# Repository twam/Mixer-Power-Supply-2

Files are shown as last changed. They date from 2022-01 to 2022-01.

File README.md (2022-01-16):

Mixer-Power-Supply-2
===

This repository is part of the USB audio mixer project described on https://www.twam.info/general/building-a-custom-usb-audio-mixer.

It supersedes http://github.com/twam/Mixer-Power-Supply.

## License

[][cc-by-sa]

This work is licensed under a [Creative Commons Attribution-NonCommercial-ShareAlike 4.0 International License][cc-by-sa].

[][cc-by-sa]

[cc-by-sa]: http://creativecommons.org/licenses/by-nc-sa/4.0/
[cc-by-sa-image]: https://licensebuttons.net/l/by-nc-sa/4.0/88x31.png
[cc-by-sa-shield]: https://img.shields.io/badge/License-CC%20BY--NC--SA%204.0-lightgrey.svg

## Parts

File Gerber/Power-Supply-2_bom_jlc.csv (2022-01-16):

Comment | Designator | Footprint | LCSC Part #
10u/50V | C1,C2,C3,C5,C6,C7 | C_1206_3216Metric | C13585
100nF | C4,C19,C8,C20,C21,C22,C11,C28,C29,C12,C30,C31,C32,C33 | C_0603_1608Metric | C14663
4u7 | C34 | C_0805_2012Metric | C1779
LL4148 | D1,D2,D3,D4,D12 | D_MiniMELF | C9808
green | D7 | LED_0603_1608Metric | C72043
red | D8,D9,D10,D11 | LED_0603_1608Metric | C2286
600R/100M | L5 | L_0805_2012Metric | C1017
AO3400A | Q1,Q2,Q3,Q5,Q4 | TSOT-23 | C20917
0R | R1,R15,R7,R22,R26,R20,R31,R34,R37 | R_0805_2012Metric | C17477
2k4 | R2 | R_0603_1608Metric | C22940
22k | R3 | R_0603_1608Metric | C31850
270k | R4,R17 | R_0603_1608Metric | C22965
3k3 | R5 | R_0805_2012Metric | C26010
11k | R6,R11,R25,R27 | R_0603_1608Metric | C25950
27k | R8 | R_0603_1608Metric | C22967
39k | R9 | R_0805_2012Metric | C23153
6k8 | R10,R28 | R_0603_1608Metric | C23212
39k | R12 | R_0603_1608Metric | C23153
0R01 | R13,R29 | R_1206_3216Metric | C308574
5k6 | R14,R36,R39,R41,R42,R43,R44 | R_0603_1608Metric | C23189
10k | R16,R23,R21,R24,R32,R33,R35,R40,R38 | R_0603_1608Metric | C25804
68k | R19,R30 | R_0603_1608Metric | C23231
1k5 | R45 | R_0603_1608Metric | C22843
RESET | SW1 | SW_SPST_B3U-1000P | C231329
INA139 | U5,U9 | SOT-23-5 | C129947
NE5532 | U7 | SOIC-8_3.9x4.9mm_P1.27mm | C7426
MCP6002-xSN | U10 | SOIC-8_3.9x4.9mm_P1.27mm | C7377

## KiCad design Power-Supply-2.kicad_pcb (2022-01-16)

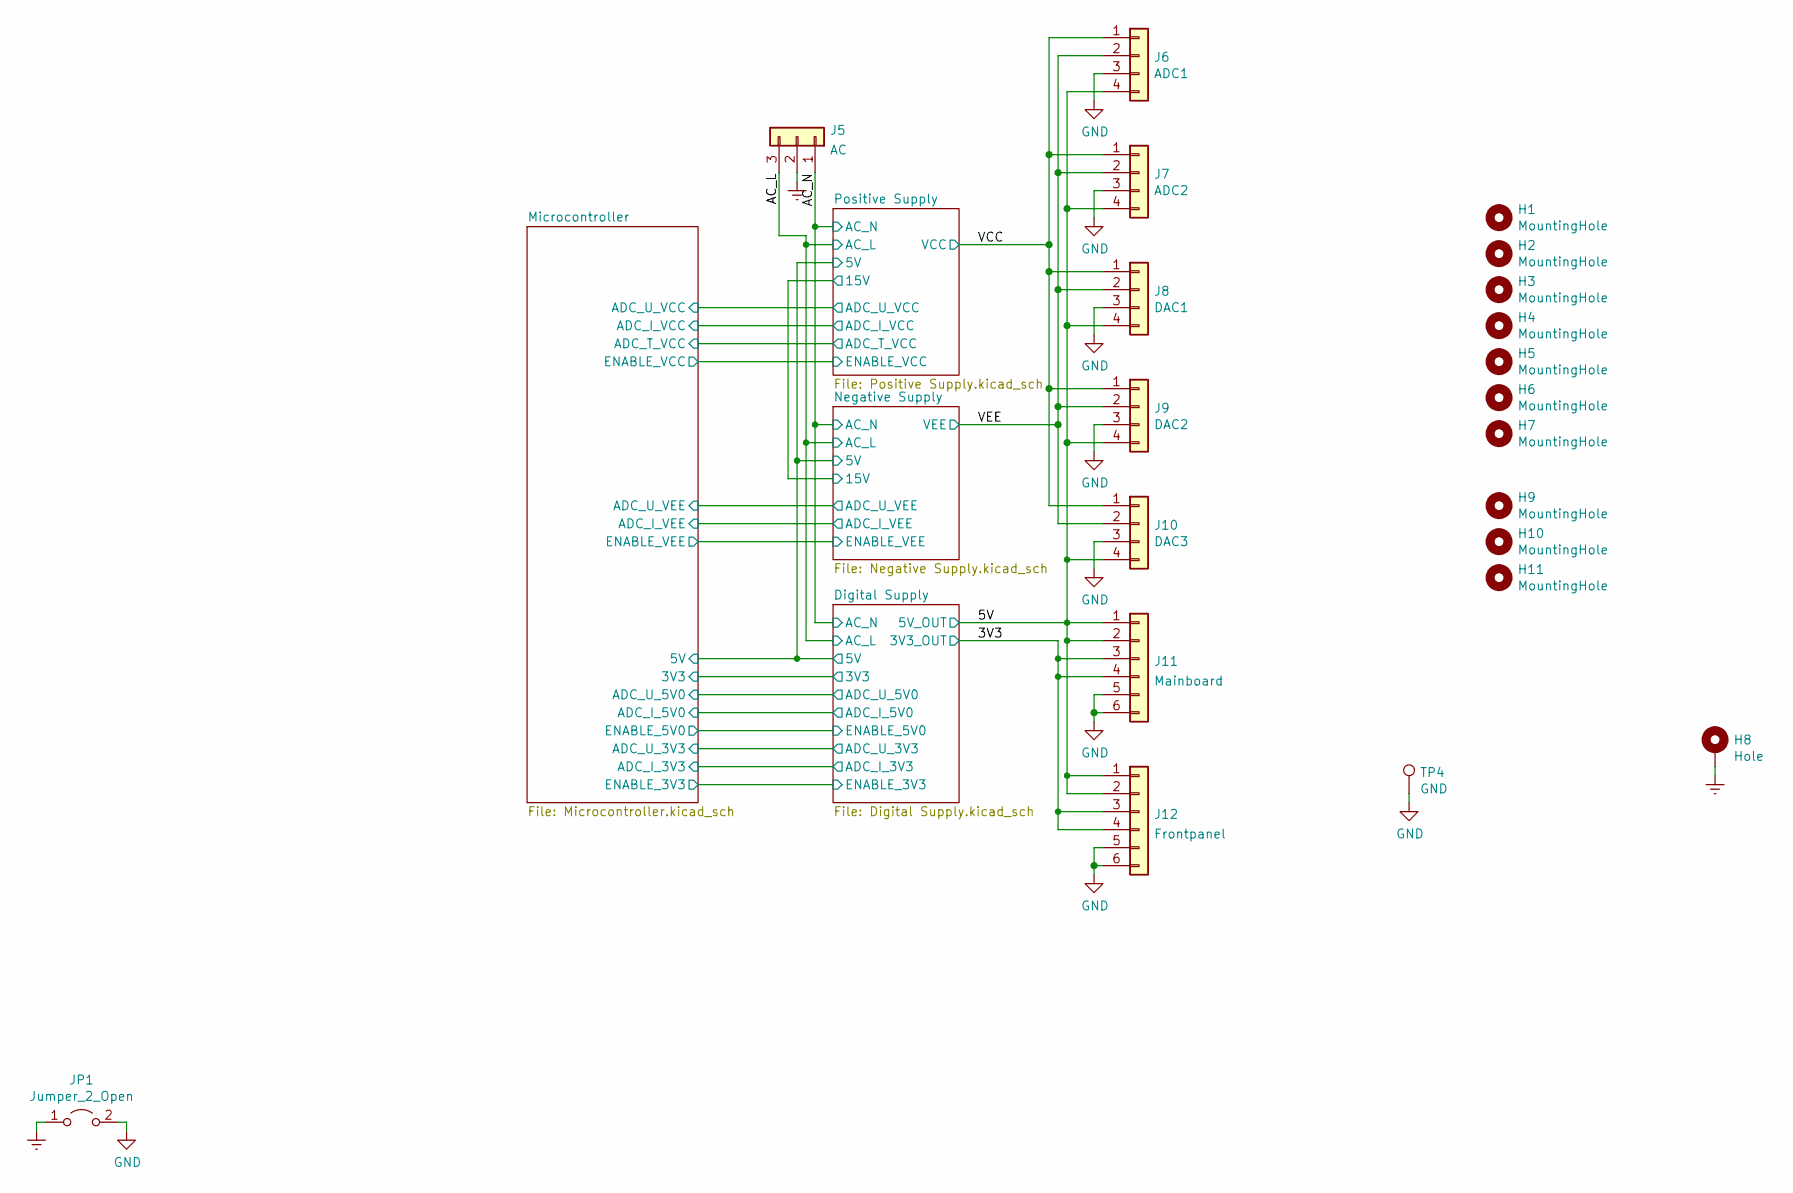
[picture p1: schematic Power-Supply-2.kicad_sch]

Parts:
H1, H2, H3, H4, H5, H6, H7: MountingHole; MountingHole_3.2mm_M3_DIN965
H8: Hole; MountingHole_3.2mm_M3_DIN965_Pad
H9, H10, H11: MountingHole; MountingHole_JLCPCB
J5: AC; JST_VH_B3P-VH_1x03_P3.96mm_Vertical
J6: ADC1; JST_VH_B4P-VH_1x04_P3.96mm_Vertical
J7: ADC2; JST_VH_B4P-VH_1x04_P3.96mm_Vertical
J8: DAC1; JST_VH_B4P-VH_1x04_P3.96mm_Vertical
J9: DAC2; JST_VH_B4P-VH_1x04_P3.96mm_Vertical
J10: DAC3; JST_VH_B4P-VH_1x04_P3.96mm_Vertical
J11: Mainboard; JST_VH_B6P-VH_1x06_P3.96mm_Vertical
J12: Frontpanel; JST_VH_B6P-VH_1x06_P3.96mm_Vertical
JP1: Jumper_2_Open; SolderJumper-2_P1.3mm_Open_RoundedPad1.0x1.5mm
TP4: GND; TestPoint_Pad_D2.0mm

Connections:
/3V3: J11.3, J11.4, J12.3, J12.4; also elsewhere on the board
/5V: J6.4, J7.4, J8.4, J9.4, J10.4, J11.1, J11.2, J12.1, J12.2; also elsewhere on the board
/AC_L: J5.3; also elsewhere on the board
/AC_N: J5.1; also elsewhere on the board
/VCC: J6.1, J7.1, J8.1, J9.1, J10.1; also elsewhere on the board
/VEE: J6.2, J7.2, J8.2, J9.2, J10.2; also elsewhere on the board
Earth: H8.1, J5.2, JP1.1 (A)
GND: J6.3, J7.3, J8.3, J9.3, J10.3, J11.5, J11.6, J12.5, J12.6, JP1.2 (B), TP4.1; also elsewhere on the board

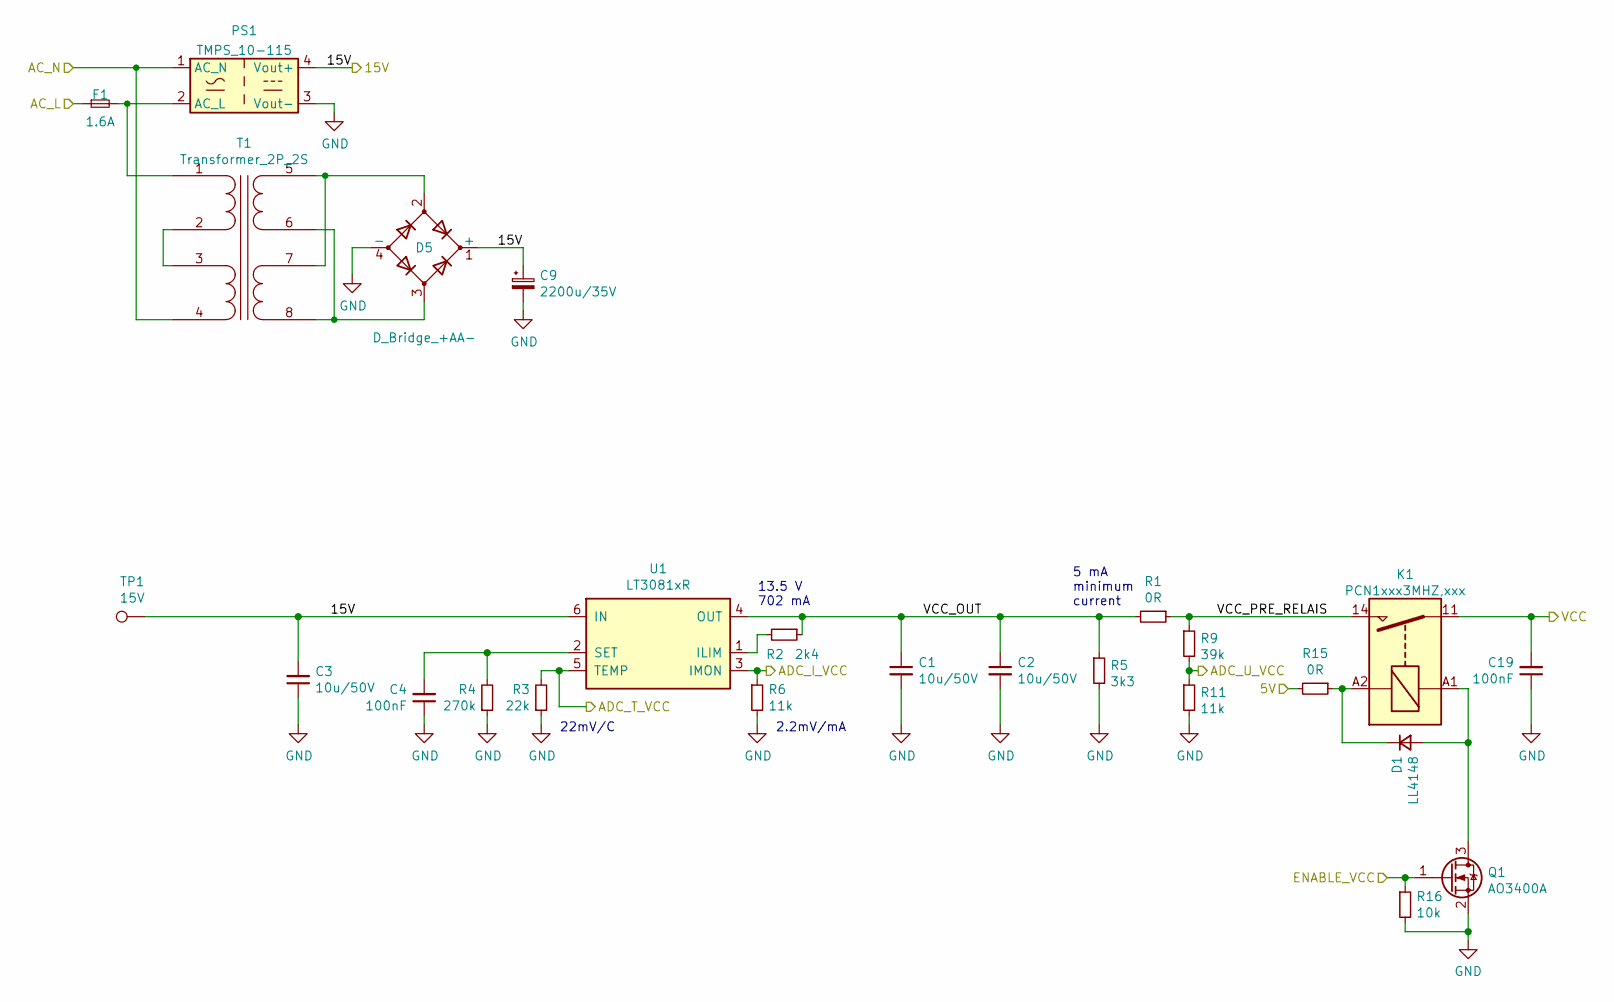
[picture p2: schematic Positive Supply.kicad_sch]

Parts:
C1, C2, C3: 10u/50V; C_1206_3216Metric; LCSC C13585
C4, C19: 100nF; C_0603_1608Metric; LCSC C14663
C9: 2200u/35V; CP_Radial_D16.0mm_P7.50mm
D1: LL4148; D_MiniMELF; LCSC C9808
D5: D_Bridge_+AA-; Diode_Bridge_Bourns_CD-HD2xxx
F1: 1.6A; Fuseholder_Cylinder-5x20mm_Schurter_0031_8201_Horizontal_Op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
K1: PCN1xxx3MHZ,xxx
PS1: TMPS_10-115; Converter_ACDC_TRACO_TMPS_10-xxx
Q1: AO3400A; TSOT-23; LCSC C20917
R1, R15: 0R; R_0805_2012Metric; LCSC C17477
R2: 2k4; R_0603_1608Metric; LCSC C22940
R3: 22k; R_0603_1608Metric; LCSC C31850
R4: 270k; R_0603_1608Metric; LCSC C22965
R5: 3k3; R_0805_2012Metric; LCSC C26010
R6, R11: 11k; R_0603_1608Metric; LCSC C25950
R9: 39k; R_0805_2012Metric; LCSC C23153
R16: 10k; R_0603_1608Metric; LCSC C25804
T1: Transformer_2P_2S; Talema_7xxxx_15VA
TP1: 15V; TestPoint_Pad_D2.0mm
U1: LT3081xR; TO-220-7_P2.54x3.8mm_StaggerOdd_Lead5.85mm_TabDown

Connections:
/AC_L: F1.1; also elsewhere on the board
/AC_N: PS1.1 (AC_N), T1.4 (OUT2B); also elsewhere on the board
/Digital Supply/5V: R15.2; also elsewhere on the board
/Microcontroller/ADC_I_VCC: R6.1, U1.3 (IMON); also elsewhere on the board
/Microcontroller/ADC_T_VCC: R3.2, U1.5 (TEMP); also elsewhere on the board
/Microcontroller/ADC_U_VCC: R9.2, R11.1; also elsewhere on the board
/Microcontroller/ENABLE_VCC: Q1.1 (G), R16.1; also elsewhere on the board
/Positive Supply/15V: C3.2, C9.1, D5.1 (+), PS1.4 (Vout+), TP1.1, U1.6 (IN); also elsewhere on the board
/Positive Supply/VCC_OUT: C1.1, C2.1, R1.2, R2.1, R5.1, U1.4 (OUT)
/Positive Supply/VCC_PRE_RELAIS: K1.14, R1.1, R9.1
/VCC: C19.2, K1.11; also elsewhere on the board
GND: C1.2, C2.2, C3.1, C4.1, C9.2, C19.1, D5.4 (-), PS1.3 (Vout-), Q1.2 (S), R3.1, R4.1, R5.2, R6.2, R11.2, R16.2; also elsewhere on the board
unnamed: C4.2, R4.2, U1.2 (SET)
unnamed: D1.1 (K), K1.A2, R15.1
unnamed: D1.2 (A), K1.A1, Q1.3 (D)
unnamed: D5.2, T1.5 (OUT1A), T1.7 (OUT2A)
unnamed: D5.3, T1.6 (OUT1B), T1.8 (OUT2B)
unnamed: F1.2, PS1.2 (AC_L), T1.1 (IN1A)
unnamed: R2.2, U1.1 (ILIM)
unnamed: T1.2 (IN1B), T1.3 (OUT2A)

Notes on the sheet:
2.2mV/mA
5 mA minimum current
22mV/C
13.5 V 702 mA

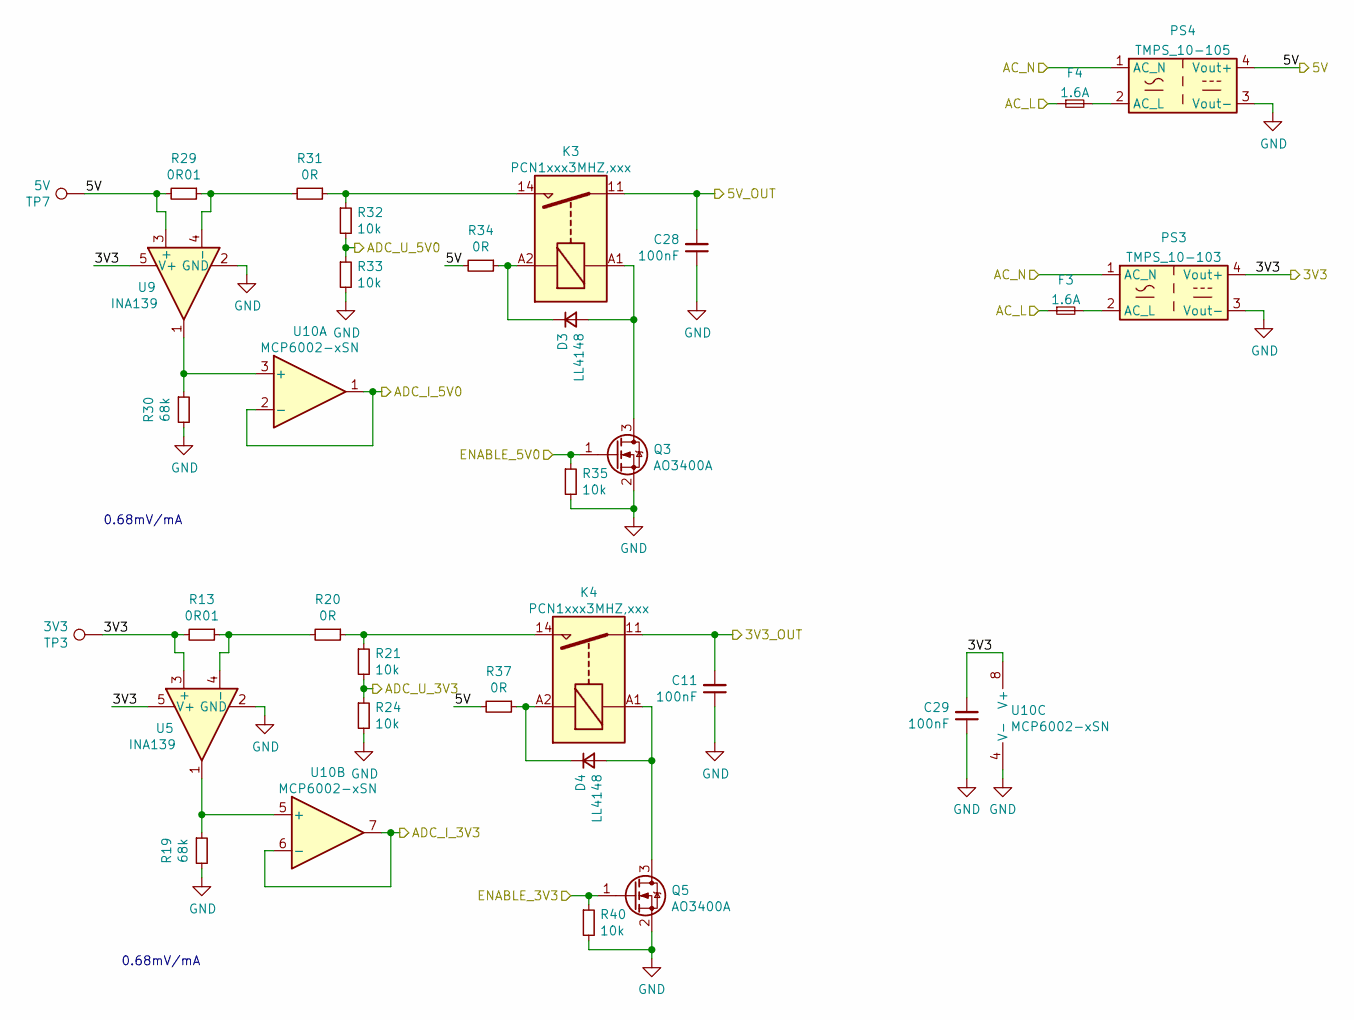
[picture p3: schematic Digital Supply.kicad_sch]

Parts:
C11, C28, C29: 100nF; C_0603_1608Metric; LCSC C14663
D3, D4: LL4148; D_MiniMELF; LCSC C9808
F3, F4: 1.6A; Fuseholder_Cylinder-5x20mm_Schurter_0031_8201_Horizontal_Op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
K3, K4: PCN1xxx3MHZ,xxx
PS3: TMPS_10-103; Converter_ACDC_TRACO_TMPS_10-xxx
PS4: TMPS_10-105; Converter_ACDC_TRACO_TMPS_10-xxx
Q3, Q5: AO3400A; TSOT-23; LCSC C20917
R13, R29: 0R01; R_1206_3216Metric; LCSC C308574
R19, R30: 68k; R_0603_1608Metric; LCSC C23231
R20, R31, R34, R37: 0R; R_0805_2012Metric; LCSC C17477
R21, R24, R32, R33, R35, R40: 10k; R_0603_1608Metric; LCSC C25804
TP3: 3V3; TestPoint_Pad_D2.0mm
TP7: 5V; TestPoint_Pad_D2.0mm
U5, U9: INA139; SOT-23-5; LCSC C129947
U10: MCP6002-xSN; SOIC-8_3.9x4.9mm_P1.27mm

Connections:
/3V3: C11.2, K4.11; also elsewhere on the board
/5V: C28.2, K3.11; also elsewhere on the board
/AC_L: F3.1, F4.1; also elsewhere on the board
/AC_N: PS3.1 (AC_N), PS4.1 (AC_N); also elsewhere on the board
/Digital Supply/3V3: C29.2, PS3.4 (Vout+), R13.2, TP3.1, U5.3 (+), U5.5 (V+), U9.5 (V+), U10.8 (V+); also elsewhere on the board
/Digital Supply/5V: PS4.4 (Vout+), R29.2, R34.2, R37.2, TP7.1, U9.3 (+); also elsewhere on the board
/Digital Supply/ADC_I_3V3: U10.6 (-), U10.7; also elsewhere on the board
/Digital Supply/ADC_I_5V0: U10.1, U10.2 (-); also elsewhere on the board
/Digital Supply/ADC_U_3V3: R21.2, R24.1; also elsewhere on the board
/Digital Supply/ADC_U_5V0: R32.2, R33.1; also elsewhere on the board
/Digital Supply/ENABLE_3V3: Q5.1 (G), R40.1; also elsewhere on the board
/Digital Supply/ENABLE_5V0: Q3.1 (G), R35.1; also elsewhere on the board
GND: C11.1, C28.1, C29.1, PS3.3 (Vout-), PS4.3 (Vout-), Q3.2 (S), Q5.2 (S), R19.2, R24.2, R30.2, R33.2, R35.2, R40.2, U5.2 (GND), U9.2 (GND), U10.4 (V-); also elsewhere on the board
unnamed: D3.1 (K), K3.A2, R34.1
unnamed: D3.2 (A), K3.A1, Q3.3 (D)
unnamed: D4.1 (K), K4.A2, R37.1
unnamed: D4.2 (A), K4.A1, Q5.3 (D)
unnamed: F3.2, PS3.2 (AC_L)
unnamed: F4.2, PS4.2 (AC_L)
unnamed: K3.14, R31.1, R32.1
unnamed: K4.14, R20.1, R21.1
unnamed: R13.1, R20.2, U5.4 (-)
unnamed: R19.1, U5.1, U10.5 (+)
unnamed: R29.1, R31.2, U9.4 (-)
unnamed: R30.1, U9.1, U10.3 (+)

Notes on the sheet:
0.68mV/mA

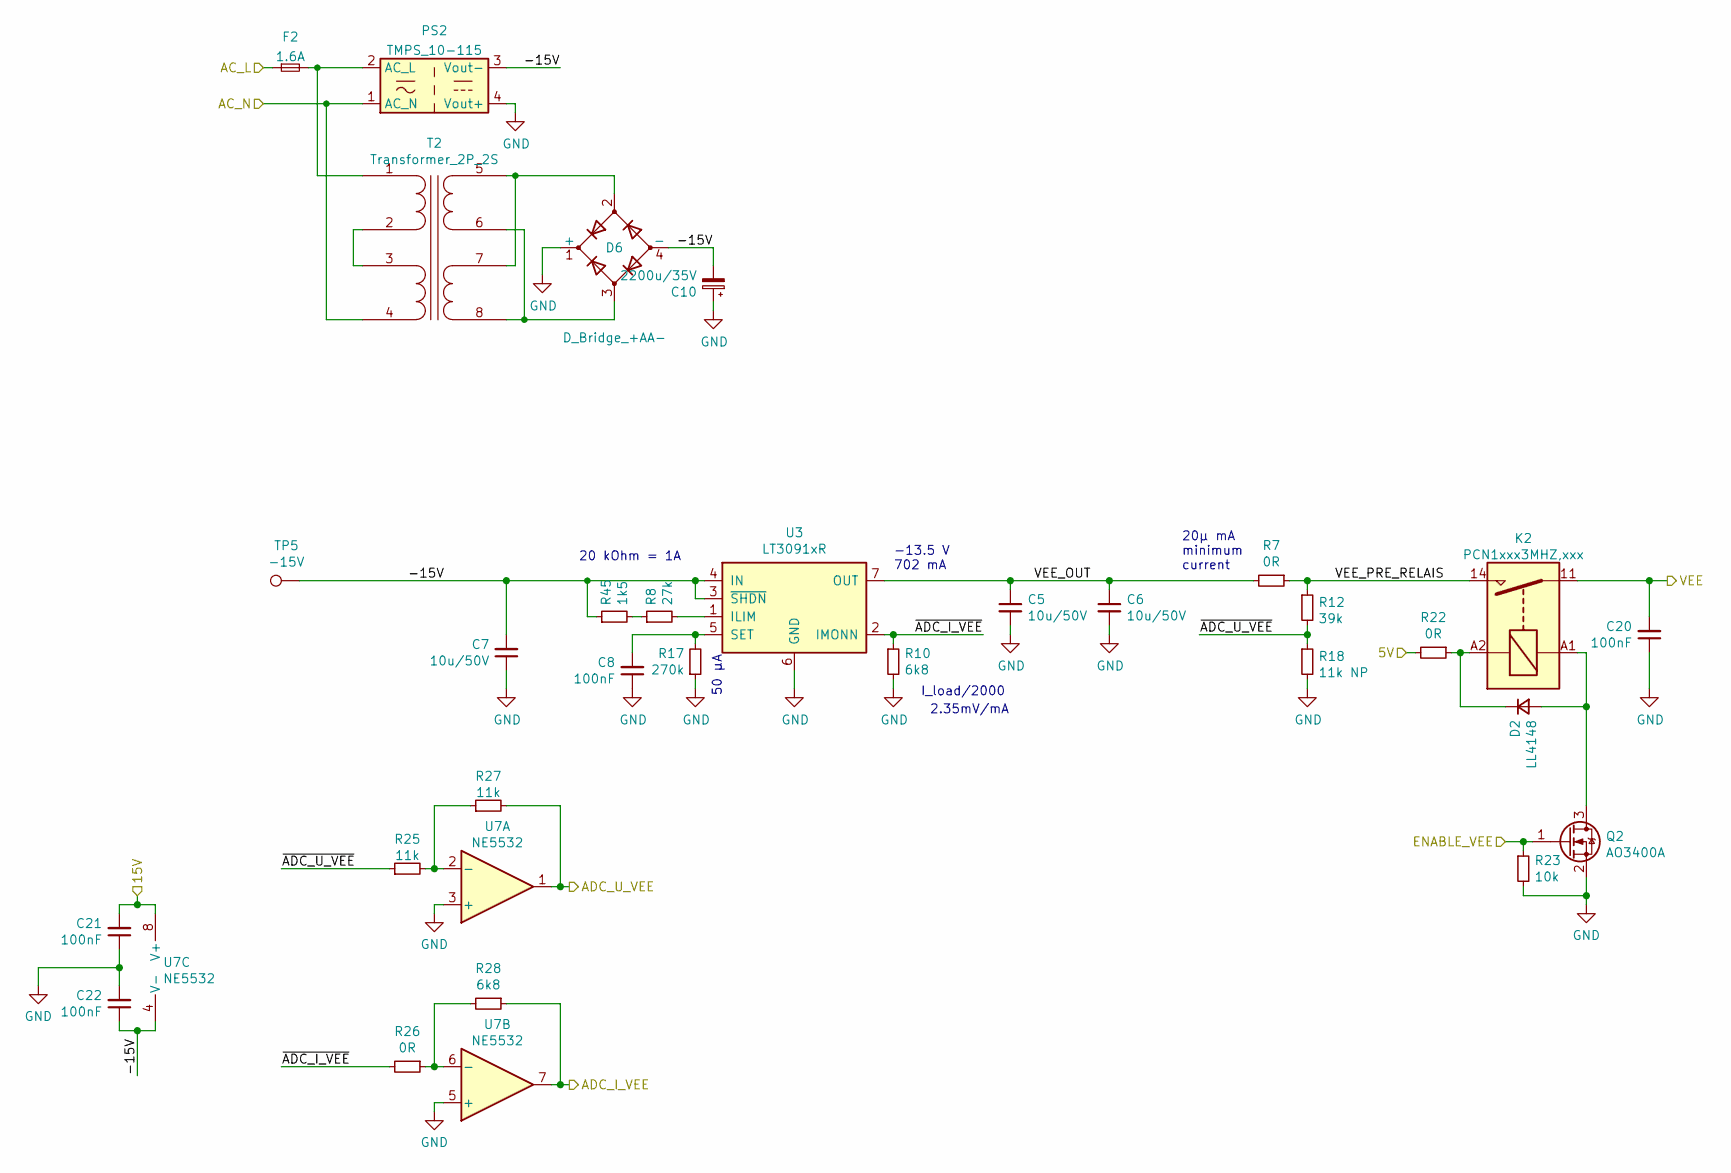
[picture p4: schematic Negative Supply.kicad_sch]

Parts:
C5, C6, C7: 10u/50V; C_1206_3216Metric; LCSC C13585
C8, C20, C21, C22: 100nF; C_0603_1608Metric; LCSC C14663
C10: 2200u/35V; CP_Radial_D16.0mm_P7.50mm
D2: LL4148; D_MiniMELF; LCSC C9808
D6: D_Bridge_+AA-; Diode_Bridge_Bourns_CD-HD2xxx
F2: 1.6A; Fuseholder_Cylinder-5x20mm_Schurter_0031_8201_Horizontal_Op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
K2: PCN1xxx3MHZ,xxx
PS2: TMPS_10-115; Converter_ACDC_TRACO_TMPS_10-xxx
Q2: AO3400A; TSOT-23; LCSC C20917
R7, R22, R26: 0R; R_0805_2012Metric; LCSC C17477
R8: 27k; R_0603_1608Metric; LCSC C22967
R10, R28: 6k8; R_0603_1608Metric; LCSC C23212
R12: 39k; R_0603_1608Metric; LCSC C23153
R17: 270k; R_0603_1608Metric; LCSC C22965
R18: 11k NP; R_0603_1608Metric
R23: 10k; R_0603_1608Metric; LCSC C25804
R25, R27: 11k; R_0603_1608Metric; LCSC C25950
R45: 1k5; R_0603_1608Metric; LCSC C22843
T2: Transformer_2P_2S; Talema_7xxxx_15VA
TP5: -15V; TestPoint_Pad_D2.0mm
U3: LT3091xR; TO-220-7_P2.54x3.8mm_StaggerOdd_Lead5.85mm_TabDown
U7: NE5532; SOIC-8_3.9x4.9mm_P1.27mm

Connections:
/AC_L: F2.1; also elsewhere on the board
/AC_N: PS2.1 (AC_N), T2.4 (OUT2B); also elsewhere on the board
/Digital Supply/5V: R22.2; also elsewhere on the board
/Microcontroller/ADC_I_VEE: R28.1, U7.7; also elsewhere on the board
/Microcontroller/ADC_U_VEE: R27.2, U7.1; also elsewhere on the board
/Microcontroller/ENABLE_VEE: Q2.1 (G), R23.1; also elsewhere on the board
/Negative Supply/-15V: C7.2, C10.2, C22.1, D6.4 (-), PS2.3 (Vout-), R45.1, TP5.1, U3.3 (~SHDN), U3.4 (IN), U7.4 (V-)
/Negative Supply/VEE_OUT: C5.1, C6.1, R7.2, U3.7 (OUT)
/Negative Supply/VEE_PRE_RELAIS: K2.14, R7.1, R12.1
/Negative Supply/~ADC_I_VEE: R10.1, R26.2, U3.2 (IMONN)
/Negative Supply/~ADC_U_VEE: R12.2, R18.1, R25.1
/Positive Supply/15V: C21.2, U7.8 (V+); also elsewhere on the board
/VEE: C20.2, K2.11; also elsewhere on the board
GND: C5.2, C6.2, C7.1, C8.1, C10.1, C20.1, C21.1, C22.2, D6.1 (+), PS2.4 (Vout+), Q2.2 (S), R10.2, R17.1, R18.2, R23.2, U3.6 (GND), U7.3 (+), U7.5 (+); also elsewhere on the board
unnamed: C8.2, R17.2, U3.5 (SET)
unnamed: D2.1 (K), K2.A2, R22.1
unnamed: D2.2 (A), K2.A1, Q2.3 (D)
unnamed: D6.2, T2.5 (OUT1A), T2.7 (OUT2A)
unnamed: D6.3, T2.6 (OUT1B), T2.8 (OUT2B)
unnamed: F2.2, PS2.2 (AC_L), T2.1 (IN1A)
unnamed: R8.1, R45.2
unnamed: R8.2, U3.1 (ILIM)
unnamed: R25.2, R27.1, U7.2 (-)
unnamed: R26.1, R28.2, U7.6 (-)
unnamed: T2.2 (IN1B), T2.3 (OUT2A)

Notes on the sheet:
20µ mA minimum current
20 kOhm = 1A
I_load/2000
50 µA
2.35mV/mA
-13.5 V 702 mA

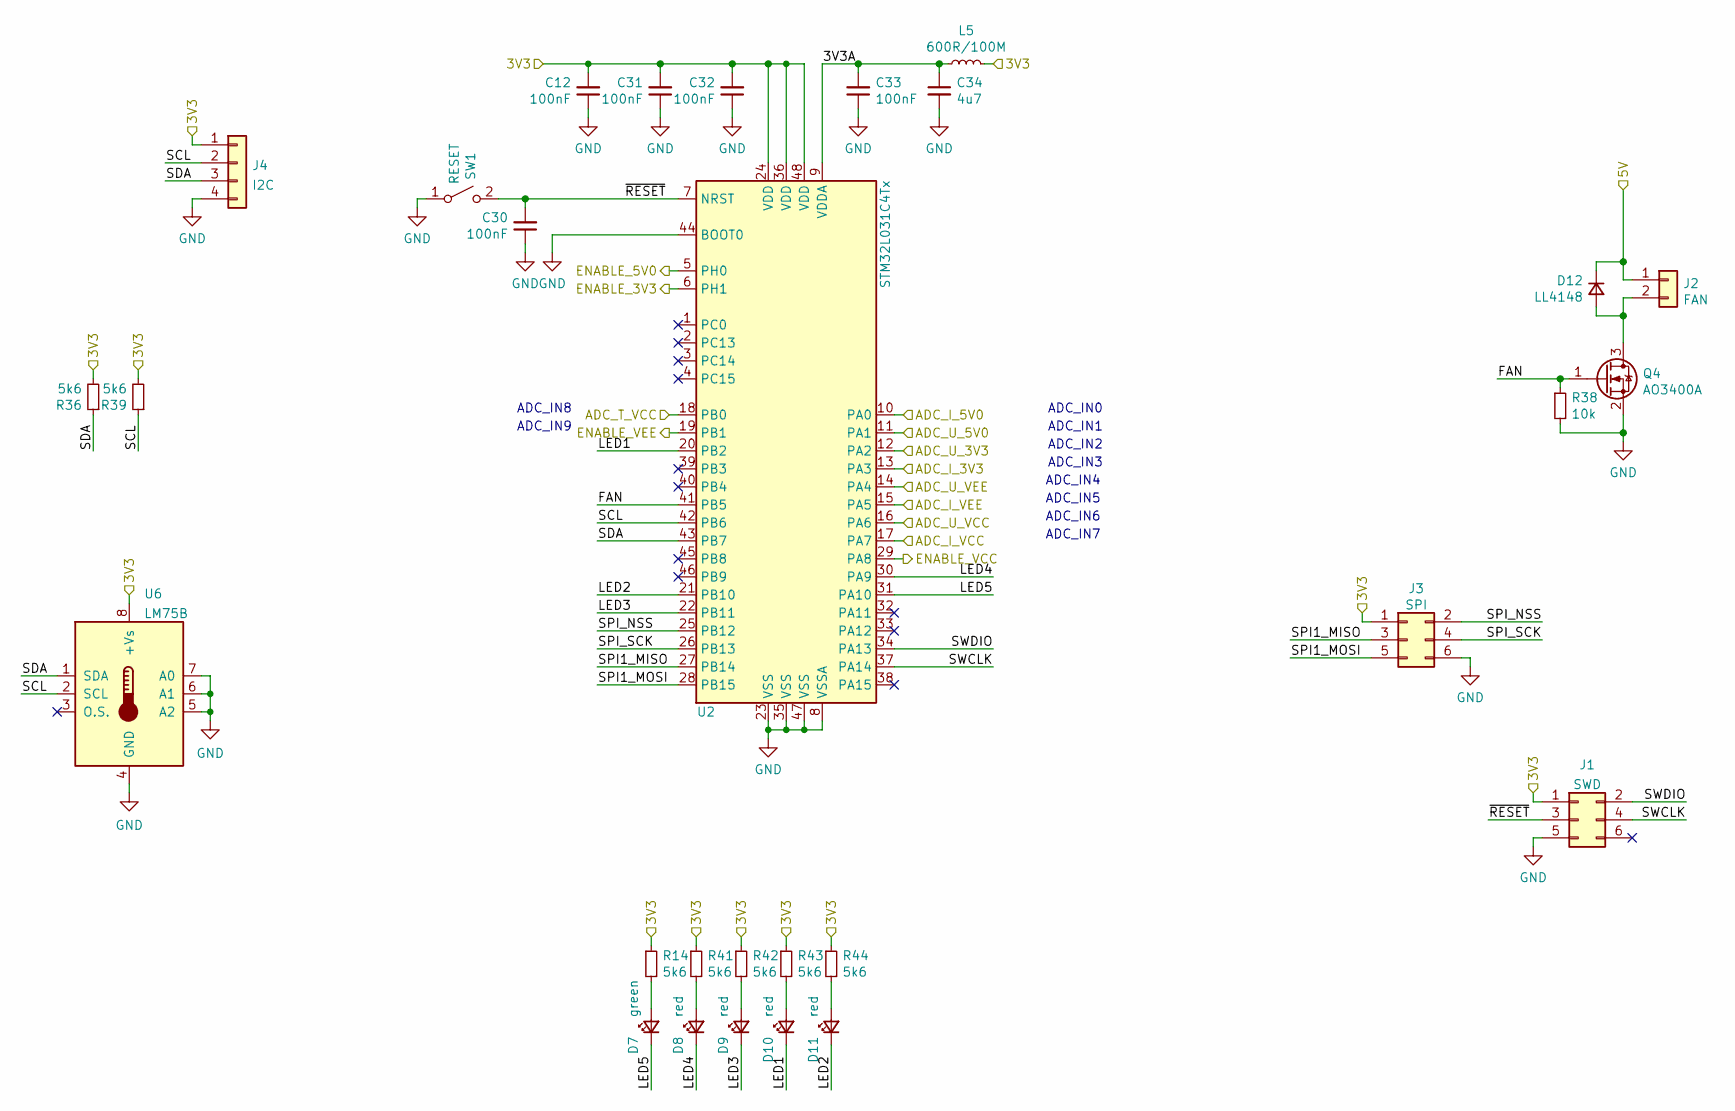
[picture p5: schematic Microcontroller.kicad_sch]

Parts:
C12, C30, C31, C32, C33: 100nF; C_0603_1608Metric; LCSC C14663
C34: 4u7; C_0805_2012Metric; LCSC C1779
D7: green; LED_0603_1608Metric; LCSC C72043
D8, D9, D10, D11: red; LED_0603_1608Metric; LCSC C2286
D12: LL4148; D_MiniMELF; LCSC C9808
J1: SWD; PinHeader_2x03_P2.54mm_Vertical
J2: FAN; Molex_KK-254_AE-6410-02A_1x02_P2.54mm_Vertical
J3: SPI; PinHeader_2x03_P2.54mm_Vertical
J4: I2C; PinHeader_1x04_P2.54mm_Vertical
L5: 600R/100M; L_0805_2012Metric; LCSC C1017
Q4: AO3400A; TSOT-23; LCSC C20917
R14, R36, R39, R41, R42, R43, R44: 5k6; R_0603_1608Metric; LCSC C23189
R38: 10k; R_0603_1608Metric; LCSC C25804
SW1: RESET; SW_SPST_B3U-1000P; LCSC C231329
U2: STM32L031C4Tx; LQFP-48_7x7mm_P0.5mm
U6: LM75B; SOIC-8_3.9x4.9mm_P1.27mm

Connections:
/Digital Supply/3V3: C12.2, C31.2, C32.2, J1.1, J3.1, J4.1, L5.2, R14.1, R36.2, R39.2, R41.1, R42.1, R43.1, R44.1, U2.24 (VDD), U2.36 (VDD), U2.48 (VDD), U6.8 (+Vs); also elsewhere on the board
/Digital Supply/5V: D12.1 (K), J2.1; also elsewhere on the board
/Digital Supply/ADC_I_3V3: U2.13 (PA3); also elsewhere on the board
/Digital Supply/ADC_I_5V0: U2.10 (PA0); also elsewhere on the board
/Digital Supply/ADC_U_3V3: U2.12 (PA2); also elsewhere on the board
/Digital Supply/ADC_U_5V0: U2.11 (PA1); also elsewhere on the board
/Digital Supply/ENABLE_3V3: U2.6 (PH1); also elsewhere on the board
/Digital Supply/ENABLE_5V0: U2.5 (PH0); also elsewhere on the board
/Microcontroller/3V3A: C33.2, C34.1, L5.1, U2.9 (VDDA)
/Microcontroller/ADC_I_VCC: U2.17 (PA7); also elsewhere on the board
/Microcontroller/ADC_I_VEE: U2.15 (PA5); also elsewhere on the board
/Microcontroller/ADC_T_VCC: U2.18 (PB0); also elsewhere on the board
/Microcontroller/ADC_U_VCC: U2.16 (PA6); also elsewhere on the board
/Microcontroller/ADC_U_VEE: U2.14 (PA4); also elsewhere on the board
/Microcontroller/ENABLE_VCC: U2.29 (PA8); also elsewhere on the board
/Microcontroller/ENABLE_VEE: U2.19 (PB1); also elsewhere on the board
/Microcontroller/FAN: Q4.1 (G), R38.1, U2.41 (PB5)
/Microcontroller/LED1: D10.1 (K), U2.20 (PB2)
/Microcontroller/LED2: D11.1 (K), U2.21 (PB10)
/Microcontroller/LED3: D9.1 (K), U2.22 (PB11)
/Microcontroller/LED4: D8.1 (K), U2.30 (PA9)
/Microcontroller/LED5: D7.1 (K), U2.31 (PA10)
/Microcontroller/SCL: J4.2, R39.1, U2.42 (PB6), U6.2 (SCL)
/Microcontroller/SDA: J4.3, R36.1, U2.43 (PB7), U6.1 (SDA)
/Microcontroller/SPI1_MISO: J3.3, U2.27 (PB14)
/Microcontroller/SPI1_MOSI: J3.5, U2.28 (PB15)
/Microcontroller/SPI_NSS: J3.2, U2.25 (PB12)
/Microcontroller/SPI_SCK: J3.4, U2.26 (PB13)
/Microcontroller/SWCLK: J1.4, U2.37 (PA14)
/Microcontroller/SWDIO: J1.2, U2.34 (PA13)
/Microcontroller/~RESET: C30.2, J1.3, SW1.2 (B), U2.7 (NRST)
GND: C12.1, C30.1, C31.1, C32.1, C33.1, C34.2, J1.5, J3.6, J4.4, Q4.2 (S), R38.2, SW1.1 (A), U2.8 (VSSA), U2.23 (VSS), U2.35 (VSS), U2.44 (BOOT0), U2.47 (VSS), U6.4 (GND), U6.5 (A2), U6.6 (A1), U6.7 (A0); also elsewhere on the board
unnamed: D7.2 (A), R14.2
unnamed: D8.2 (A), R41.2
unnamed: D9.2 (A), R42.2
unnamed: D10.2 (A), R43.2
unnamed: D11.2 (A), R44.2
unnamed: D12.2 (A), J2.2, Q4.3 (D)

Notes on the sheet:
ADC_IN7
ADC_IN6
ADC_IN3
ADC_IN4
ADC_IN5
ADC_IN0
ADC_IN8
ADC_IN9
ADC_IN2
ADC_IN1

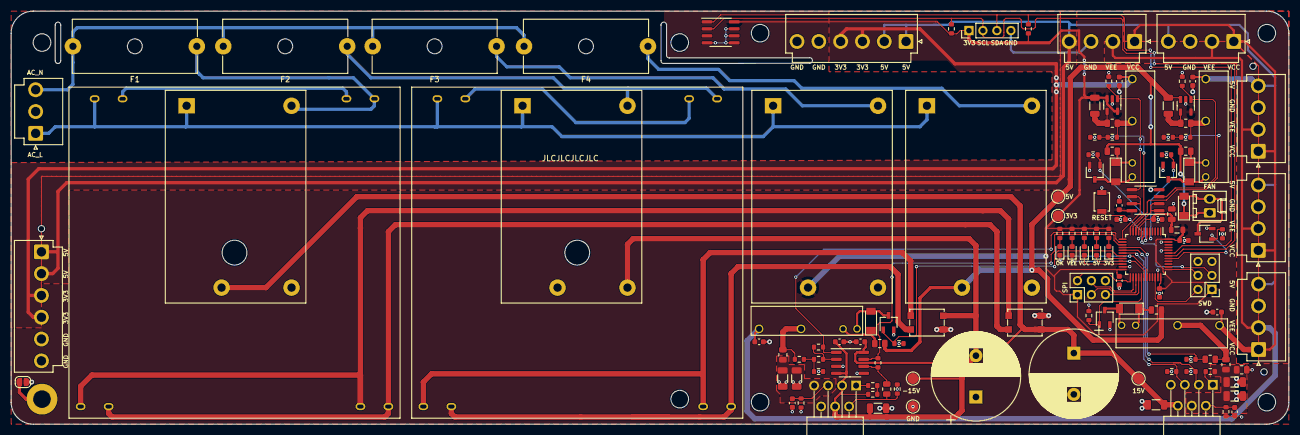
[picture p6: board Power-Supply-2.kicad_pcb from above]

Board: 2 copper layers, 232.0 x 75.0 mm, 138 parts (0 on the bottom side), 84 nets.

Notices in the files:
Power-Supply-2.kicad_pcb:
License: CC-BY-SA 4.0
